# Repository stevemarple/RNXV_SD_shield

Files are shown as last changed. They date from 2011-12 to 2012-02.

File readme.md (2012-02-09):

# RN-XV and SD shield

The RN-XV and SD shield is designed for the Arduino. It provides an
interface to the Roving Networks RN-XV Wifi module, which uses the
pseudo-standard XBee footprint. XBee modules will probably work 
although the circuitry is designed for the UART interface and GPIOs
of the RN-XV. The shield also provides an interface to an SD card and
the MicroMag3 magnetometer module by PNI. The shield can operate at
either 3.3V or 5V; logic-gate level shifters ensure that the inputs
*and* outputs of the RN-XV and SD card are only exposed to 3.3V signals.
For 5V operation the MicroMag module is powered at 5V.

The shield is fully functional on a standard Arduino (Duemilanove, 
Uno etc). Optional features such as flow control and the GPIO features
of the RN-XV require an Arduino Mega(2560) or Calunium
(https://github.com/stevemarple/Calunium). For more information see
http://blog.stevemarple.co.uk/2011/12/rn-xvsd-shield.html.

## Pin mapping

*   D4: SD select (if jumper JP3 fitted in LH position)
*   D5: RN-XV GPIO5 (if jumper JP5 fitted)
*   D8:  RN-XV GPIO6  (if jumper JP8 fitted)
*   D9:  RN-XV GPIO8 (if jumper JP6 fitted)
*   D11: MOSI (if jumper JP7 fitted)
*   D12: MISO (if jumper JP9 fitted)
*   D13: SCK (if jumper JP10 fitted)
*   D14 (Arduino Mega) or D22 (Calunium): RN-XV CTS (if jumper JP4 fitted)
*   D15 (Arduino Mega) or D23 (Calunium): RN-XV RTS (if jumper JP12 fitted)
*   A0: MicroMag SS
*   A1: RN-XV GPIO4 (if jumper JP11 fitted)
*   A2: LM61 temperature sensor
*   A3: MicroMag reset, LM61 power and heartbeat LED
*   A6: SD select (if jumper JP3 fitted in RH position)
*   A8 (Arduino Mega) or D14 (Calunium): MicroMag DRDY

## Jumper settings

*   JP1: Shield power supply; voltage regulator or 3.3V supply
*   JP2: Voltage regulator input; from +5V or Vin
*   JP3: SD chip select; D4 or A6
*   JP4: CTS flow control; D14 (Arduino Mega) or D22 (Calunium)
*   JP5: GPIO5; D5
*   JP6: GPIO8; D9
*   JP7: MOSI; link MOSI to D11
*   JP8: GPIO6; D8
*   JP9: MISO; link MISO to D12
*   JP10: SCK; link SCK to D13
*   JP11: GPIO4; A1
*   JP12: RTS flow control; D15 (Arduino Mega) or D23 (Calunium)
*   X2: TX/RX selection, any of D0,D1,D2,D3. Also D19/D18 (RX1/TX1) for
        Arduino Mega or D2/D3 (RX1/TX1) for Calunium

## Arduino library 

An Arduino library to take advantage of the various features is
provided.

## See also

*   Calunium: https://github.com/stevemarple/Calunium
*   MicroMag Arduino library: https://github.com/stevemarple/MicroMag

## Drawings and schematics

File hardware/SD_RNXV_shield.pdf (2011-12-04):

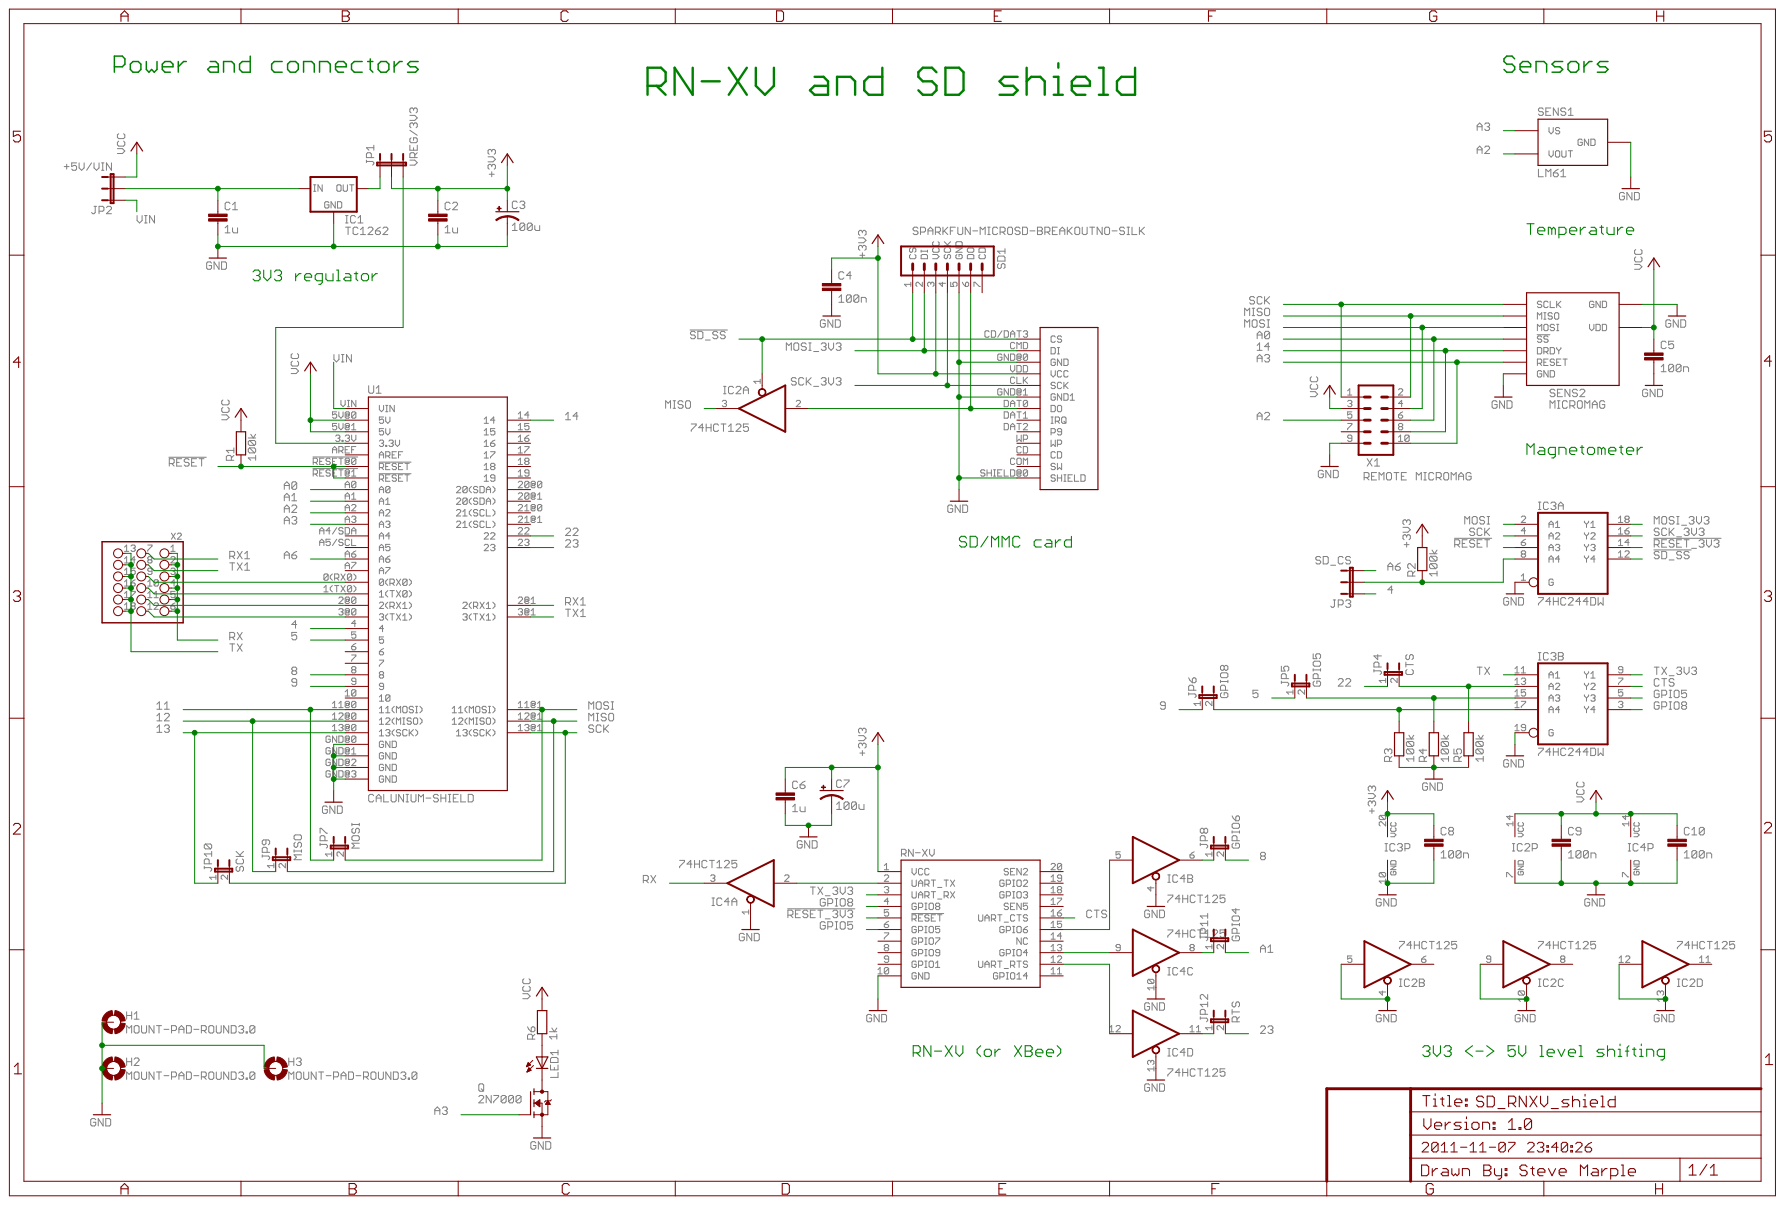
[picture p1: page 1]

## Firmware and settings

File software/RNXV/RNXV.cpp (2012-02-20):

#include "RNXV.h"

// Use the readLine() function from IniFile
#include "SD.h"
#include "IniFile.h"

const uint8_t RNXV::unconnectedPin = RNXV_UNCONNECTED_PIN;

RNXV::RNXV(Stream &uartStream) : uart(uartStream)
{
  // Mark input/output pins unconnected
  gpio4Pin = gpio5Pin = gpio6Pin = gpio8Pin = cmdPin = unconnectedPin;
  debug = false;
  errno = exitOk;
  console = NULL; // no console by default
}

bool RNXV::commandMode(void) const
{
  return uartCommandMode();
  
  if (cmdPin == unconnectedPin)
    return uartCommandMode();
  else {
    if (gpioCommandMode())
      return true;
    else
    return uartCommandMode();
  }
}

bool RNXV::uartCommandMode(void) const
{
  delay(250);
  uart.print("$$$");
  delay(250);
  // Send <CR> in case already in command mode.
  uart.print('\r');
  if (console && debug)
    console->println("$$$");
  errno = exitOk; 
  return true; // Have no easy means to check
}

bool RNXV::gpioCommandMode() const
{
  if (cmdPin == unconnectedPin) {
    errno = errorCmdPinNotSet; 
    return false;
  }

  if (console && debug)
    console->println("cmd_GPIO");

  uint8_t ctsPinOrigState;
  if (ctsPin != unconnectedPin) {
    ctsPinOrigState = digitalRead(ctsPin);
    digitalWrite(ctsPin, HIGH); // Don't allow new data to be sent
  }
  digitalWrite(cmdPin, HIGH);
  uart.flush();
  if (ctsPin != unconnectedPin)
    digitalWrite(ctsPin, LOW); // Allow sending of data
  
  uart.print('\r');
  // Read in '?', with a timeout
  char c;
  int i = uart.readBytes(&c, 1);
  digitalWrite(cmdPin, LOW);
  if (ctsPin != unconnectedPin)
    digitalWrite(ctsPin, ctsPinOrigState);

  if (i == 0) {
    errno = errorTimeout; 
    return false;
  }
  if (c == '?') {
    errno = exitOk; 
    return true;
  }
  errno = errorNotInCmdMode;
  return false;
}

void RNXV::setRtsPin(uint8_t pin)
{
  rtsPin = pin;
  if (rtsPin != unconnectedPin)
    pinMode(rtsPin, INPUT);
}

// High indicates receiver buffer full, so inver the return value
bool RNXV::rts(void) const
{
  if (rtsPin == unconnectedPin)
    return true; // Can't tell, assume it is
  return !digitalRead(rtsPin);
}

void RNXV::setCtsPin(uint8_t pin)
{
  ctsPin = pin;
  if (ctsPin != unconnectedPin)
    pinMode(ctsPin, OUTPUT);
}

// Low on RN-XV CTS pin enables transmitter so invert the state
bool RNXV::cts(bool a) const
{
  if (ctsPin == unconnectedPin)
    return false; 
  digitalWrite(ctsPin, !a);
  return true;
}

// Toggle the state of the 
bool RNXV::ctsWake(void) const
{
  if (ctsPin == unconnectedPin)
    return false; 
  uint8_t orig = digitalRead(ctsPin);
  digitalWrite(ctsPin, !orig);
  delayMicroseconds(1);
  digitalWrite(ctsPin, orig);
  return true;
}

void RNXV::setGpio4Pin(uint8_t pin)
{
  gpio4Pin = pin;
  if (gpio4Pin != unconnectedPin)
    pinMode(gpio4Pin, INPUT);
}

bool RNXV::isAssociated(void) const
{
  if (gpio4Pin == unconnectedPin) {
    errno = errorGpio4PinNotSet;
    return true;
  }
  errno = exitOk;
  return digitalRead(gpio4Pin);
}

// GPIO5
void RNXV::setGpio5Pin(uint8_t pin)
{
  gpio5Pin = pin;
  if (gpio5Pin != unconnectedPin)
    pinMode(gpio5Pin, OUTPUT);
}

bool RNXV::openConnection(void) const
{
  if (gpio5Pin == unconnectedPin)
    return false;
  digitalWrite(gpio5Pin, HIGH);
  return true;
}

bool RNXV::closeConnection(void) const
{
  if (gpio5Pin == unconnectedPin)
    return false;
  digitalWrite(gpio5Pin, LOW);
  return true;
}

// GPIO6
void RNXV::setGpio6Pin(uint8_t pin)
{
  gpio6Pin = pin;
  if (gpio6Pin != unconnectedPin) {
    pinMode(gpio6Pin, INPUT);
    digitalWrite(gpio6Pin, LOW);
  }
}

bool RNXV::isConnected(void) const
{
  if (gpio6Pin == unconnectedPin) {
    errno = errorGpio6PinNotSet;
    return true;
  }
  errno = exitOk;
  return digitalRead(gpio6Pin);
}

void RNXV::setGpio8Pin(uint8_t pin)
{ 
  gpio8Pin = pin;
  if (gpio8Pin != unconnectedPin) {
    pinMode(gpio8Pin, OUTPUT);
    digitalWrite(gpio8Pin, LOW);
  }
}

void RNXV::setCmdPin(uint8_t pin)
{ 
  cmdPin = pin;
  if (cmdPin != unconnectedPin) {
    // The command pin must change LOW-HIGH-LOW; initialise LOW
    pinMode(cmdPin, OUTPUT);
    digitalWrite(cmdPin, LOW);
  }
}

// Sleep using GPIO8 requires a rising edge, return to low level afterwards
bool RNXV::gpio8Sleep(void) const
{
  if (gpio8Pin == unconnectedPin) {
    errno = errorGpio8PinNotSet;
    return false;
  }
  digitalWrite(gpio8Pin, HIGH);
  delayMicroseconds(1);
  digitalWrite(gpio8Pin, LOW);
  return true;
}


bool RNXV::sendCommand(const char* cmd) const
{
  uart.print(cmd);
  uart.print('\r');
  if (console && debug) {
    console->println(cmd);
    delay(50);
    while (uart.available())
      console->print(char(uart.read()));
    console->println();
  }
  errno = exitOk;
  return true;  
}

bool RNXV::sendCommandsFromFile(const char* filename, char* buffer,
				  int bufferLen) const
{
  File file = SD.open(filename);
  if (!file) {
    if (console && debug) {
      console->print("sendCommandsFromFile(): cannot open ");
      console->println(filename);
    }
    errno = errorCannotOpenFile;
    return false;
  }

  bool ret = true;
  uint32_t pos = 0;
  while (1) {
    int8_t r = IniFile::readLine(file, buffer, bufferLen, pos);
    if (r < 0) {
      ret = false;
      break;
    }
    uart.flush();
    sendCommand(buffer);
    if (r)
      break;
  }
  file.close();
  uart.flush();
  errno = exitOk;
  return ret;
}

bool RNXV::connect(const char* hostname, uint16_t port, uint16_t timeout_ms) const
{
  uart.print("open ");
  uart.print(hostname);
  uart.print(' ');
  uart.print(port, DEC);
  uart.print('\r');
  if (console && debug) {
    console->print("open ");
    console->print(hostname);
    console->print(' ');
    console->println(port, DEC);
    // delay(50);
    // while (uart.available())
    //   console->print(char(uart.read()));
    // console->println();
  }
  unsigned long t = millis();
  while (!isConnected())
    if (millis() - t > timeout_ms) {
      errno = errorTimeout;
      return false;
    }

  errno = exitOk;
  return true;  
}

bool RNXV::connect(const IPAddress& ip, uint16_t port, uint16_t timeout_ms) const
{
  if (!isAssociated())
    return false; // errno already set
  uart.print("open ");
  uart.print(ip);
  uart.print(' ');
  uart.print(port, DEC);
  uart.print('\r');
  if (console && debug) {
    uart.print("open ");
    uart.print(ip);
    uart.print(' ');
    uart.println(port, DEC);
    delay(50);
    while (uart.available())
      console->print(char(uart.read()));
    console->println();
  }
  unsigned long t = millis();
  while (!isConnected())
    if (millis() - t > timeout_ms) {
      errno = errorTimeout;
      return false;
    }
  
  errno = exitOk;
  return true;  
}

bool RNXV::stop(void) const
{
  return sendCommand("close");
}
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

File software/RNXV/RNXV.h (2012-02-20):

#ifndef RNXV_H
#define RNXV_H
#include "Arduino.h"
#include "IPAddress.h"

#define RNXV_UNCONNECTED_PIN 0xff

#ifdef CALUNIUM
#define RNXV_DEFAULT_RTS 23
#define RNXV_DEFAULT_CTS 22
#define RNXV_DEFAULT_GPIO4 A1
#define RNXV_DEFAULT_GPIO5 5
#define RNXV_DEFAULT_GPIO6 8
#define RNXV_DEFAULT_GPIO8 9
#define RNXV_DEFAULT_CMD_PIN RNXV_UNCONNECTED_PIN

#elif defined(__AVR_ATmega1280__) || defined( __AVR_ATmega2560__)
#define RNXV_DEFAULT_RTS 15
#define RNXV_DEFAULT_CTS 14
#define RNXV_DEFAULT_GPIO4 A1
#define RNXV_DEFAULT_GPIO5 5
#define RNXV_DEFAULT_GPIO6 8
#define RNXV_DEFAULT_GPIO8 9
#define RNXV_DEFAULT_CMD_PIN RNXV_UNCONNECTED_PIN

#else
// Assume normal Arduino
#define RNXV_DEFAULT_RTS RNXV_UNCONNECTED_PIN
#define RNXV_DEFAULT_CTS RNXV_UNCONNECTED_PIN
#define RNXV_DEFAULT_GPIO4 A1
#define RNXV_DEFAULT_GPIO5 5
#define RNXV_DEFAULT_GPIO6 8
#define RNXV_DEFAULT_GPIO8 9
#define RNXV_DEFAULT_CMD_PIN RNXV_UNCONNECTED_PIN
#endif

#define RNXV_TIMEOUT_MS 4000

class RNXV {
 public:
  enum returnValues {
    exitOk = 0,
    errorCannotOpenFile,
    errorRtsPinNotSet,
    errorCtsPinNotSet,
    errorGpio4PinNotSet,
    errorGpio5PinNotSet,
    errorGpio6PinNotSet,
    errorGpio8PinNotSet,
    errorCmdPinNotSet,
    errorNotInCmdMode,
    errorTimeout,
    errorNotAssociated,
    errorConnectionFailed,
  };
    
  static const uint8_t unconnectedPin;
  RNXV(Stream& uartStream);

  inline returnValues getErrno(void) const {
    return errno;
  }

  inline void clearErrno(void) const {
    errno = exitOk;
  }
  
  inline bool getDebug(void) const {
    return debug;
  }

  inline void setDebug(bool myDebug = true) {
    debug = myDebug;
  }

  inline Stream& getUart(void) const {
    return uart;
  }

  inline Stream* getConsolePtr(void) const {
    return console;
  }

  inline void setConsole(Stream &stream) {
    console = &stream;
  }

  template<class T> inline Print& operator<<(T arg) const {
    uart.print(arg);
    return uart; 
  }
  
  template<class T> inline void print(T arg) const {
      uart.print(arg);
  }

  template<class T> inline void println(T arg) const {
      uart.println(arg);
  }

  inline void flush(void) const {
    uart.flush();
  }
  
  bool commandMode(void) const;
  bool uartCommandMode(void) const;
  bool gpioCommandMode(void) const;
  
  // RTS
  void setRtsPin(uint8_t p = RNXV_DEFAULT_RTS);
  bool rts(void) const;
  inline uint8_t getRtsPin(void) const {
    return rtsPin;
  }
  
  // CTS
  void setCtsPin(uint8_t p = RNXV_DEFAULT_CTS);
  bool cts(bool a) const;
  bool ctsWake(void) const;
  inline uint8_t getCtsPin(void) const {
    return ctsPin;
  }
  
  // GPIO4
  void setGpio4Pin(uint8_t p = RNXV_DEFAULT_GPIO4);
  bool isAssociated(void) const;
  inline uint8_t getGpio4Pin(void) const {
    return gpio4Pin;
  }

  // GPIO5
  void setGpio5Pin(uint8_t p = RNXV_DEFAULT_GPIO5);
  bool openConnection(void) const;
  bool closeConnection(void) const;
  inline uint8_t getGpio5Pin(void) const {
    return gpio5Pin;
  }
  
  // GPIO6
  void setGpio6Pin(uint8_t p = RNXV_DEFAULT_GPIO6);
  bool isConnected(void) const;
  inline uint8_t getGpio6Pin(void) const {
    return gpio6Pin;
  }

  // GPIO8
  void setGpio8Pin(uint8_t p = RNXV_DEFAULT_GPIO8);
  bool gpio8Sleep(void) const;
  inline uint8_t getGpio8Pin(void) const {
    return gpio8Pin;
  }
  
  bool sendCommand(const char* cmd) const;
  bool sendCommandsFromFile(const char* filename, char* buffer,
			      int bufferLen) const;
  bool connect(const char* hostname, uint16_t port,
	       uint16_t timeout_ms = RNXV_TIMEOUT_MS) const;
  bool connect(const IPAddress& ip, uint16_t port,
	       uint16_t timeout_ms = RNXV_TIMEOUT_MS) const;
  bool stop(void) const;

  // For Ethernet compatibility
  inline bool connected(void) const { return isConnected(); }

  // Command-mode pin. This can be any available GPIO that isn't being
  // used for something else
  void setCmdPin(uint8_t p = RNXV_DEFAULT_CMD_PIN);
  inline uint8_t getCmdPin(void) const {
    return cmdPin;
  }
  
  void showPinStatus(void) const;
  void consoleDebugger();
  
 private:
  mutable returnValues errno; // Error number
  uint8_t rtsPin;
  uint8_t ctsPin;
  uint8_t gpio4Pin;
  uint8_t gpio5Pin;
  uint8_t gpio6Pin;
  uint8_t gpio8Pin;
  uint8_t cmdPin;
  bool debug;
  Stream& uart;
  Stream* console; // use a pointer, might not have a console

  // Remove trailing CR, NL and other whitespace
  static void trimInput(char* str);
};

#endif

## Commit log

2012-01-12 Adding pin mapping information to readme
2012-01-12 Adding the RNXV_SD library.
    [SD_RNXV_shield.brd, SD_RNXV_shield.sch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]
2012-01-13 Fixing directory name to match RNXV class name
    [LoopbackTest.ino, RNXV.cpp, RNXV.h]
2012-01-29 Fixing debugging information so as to not interfere with operation.
    [RNXV.cpp]
2012-02-20 Fixing sendCommandsFromFile to send last line of file.
    [RNXV.cpp, RNXV.h]
